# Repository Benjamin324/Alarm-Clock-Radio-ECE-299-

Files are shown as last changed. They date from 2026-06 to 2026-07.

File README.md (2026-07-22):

# ECE 299 Design Project
## University of Victoria

This is a design project for ECE 299, Introduction to Electrical Engineering Design, at the University of Victoria.

The goal of this design course is to prototype, develop, and manufacture a clock radio based on the Raspberry Pi Pico. Design elements include Python code running on the RPi, KiCAD schematic and PCB design, and SolidWorks enclosure design.

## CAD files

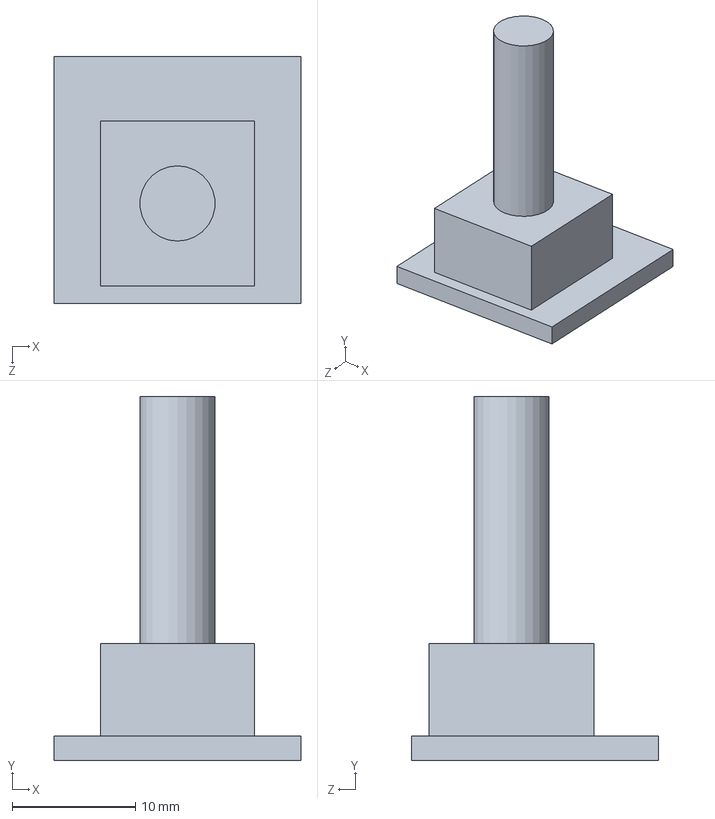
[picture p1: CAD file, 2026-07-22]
Enclosure/Encoder.SLDPRT
20.0 x 29.5 x 20.0 mm

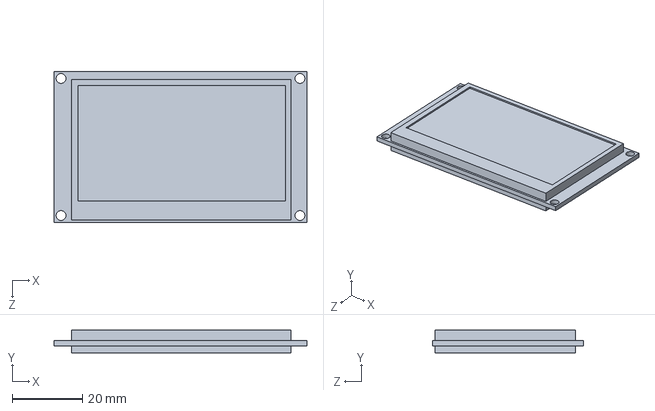
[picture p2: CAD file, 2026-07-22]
Enclosure/Display.SLDPRT
72.0 x 6.50 x 43.0 mm

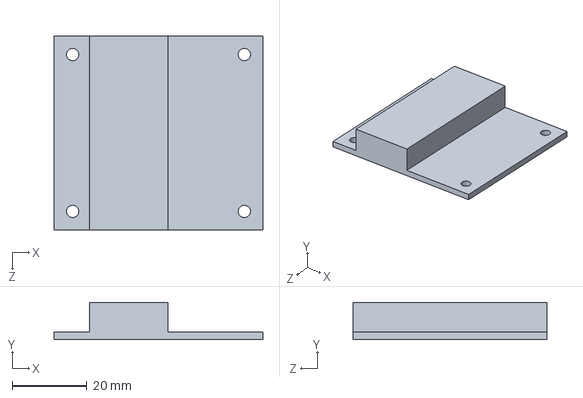
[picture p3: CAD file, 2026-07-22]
Enclosure/Mobo.SLDPRT
56.0 x 10.0 x 52.0 mm

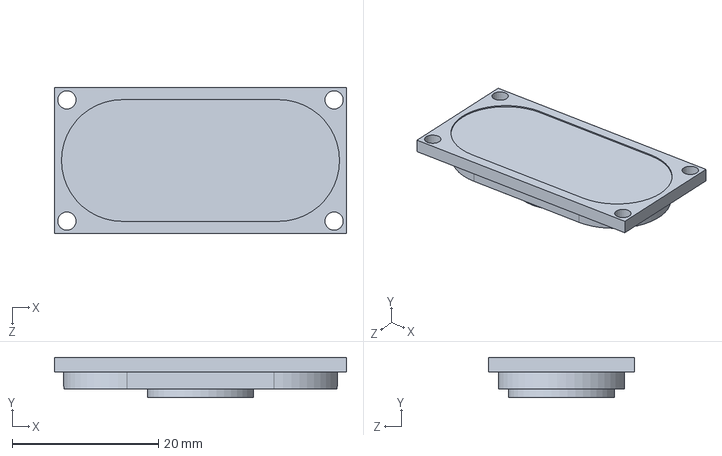
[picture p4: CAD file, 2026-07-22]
Enclosure/Speaker.SLDPRT
40.0 x 5.50 x 20.0 mm

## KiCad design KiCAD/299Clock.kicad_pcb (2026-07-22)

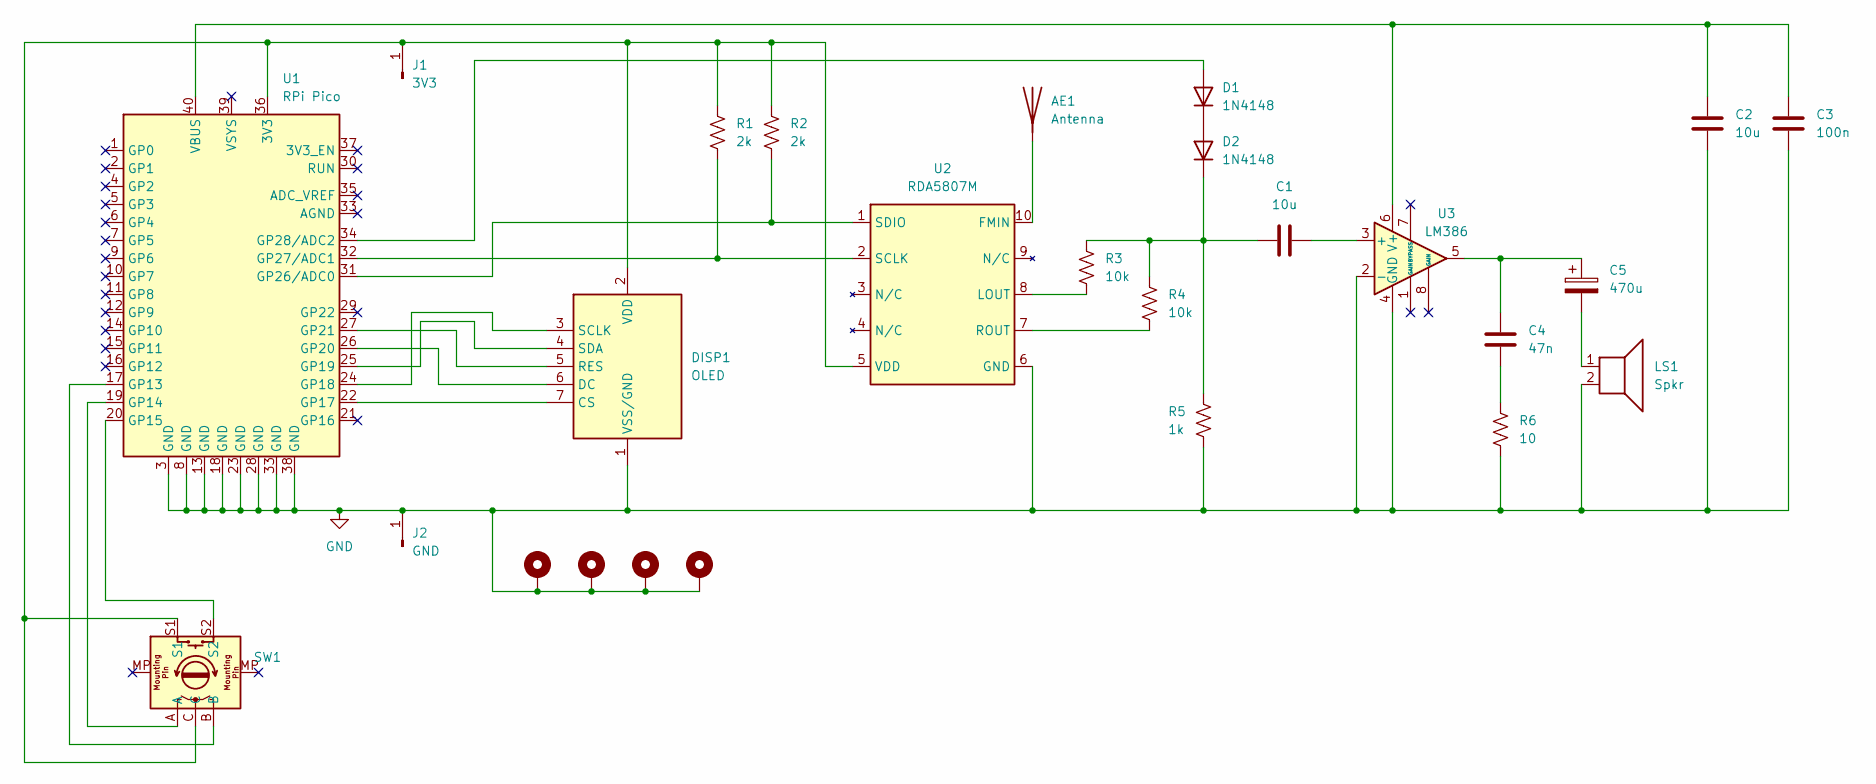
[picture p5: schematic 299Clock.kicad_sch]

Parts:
AE1: Antenna; SolderWire-0.1sqmm_1x01_D0.4mm_OD1mm
C1, C2: 10u; C_Rect_L7.0mm_W2.5mm_P5.00mm
C3: 100n; C_Rect_L7.0mm_W2.5mm_P5.00mm
C4: 47n; C_Rect_L7.0mm_W2.5mm_P5.00mm
C5: 470u; CP_Radial_D5.0mm_P2.50mm
D1, D2: 1N4148; D_DO-35_SOD27_P7.62mm_Horizontal
DISP1: OLED; PinHeader_1x07_P2.54mm_Vertical
H1, H2, H3, H4: MountingHole_Pad; MountingHole_3.2mm_M3_DIN965_Pad_TopBottom
J1: 3V3; SolderWire-0.1sqmm_1x01_D0.4mm_OD1mm
J2: GND; SolderWire-0.1sqmm_1x01_D0.4mm_OD1mm
LS1: Spkr; SolderWire-0.1sqmm_1x02_P3.6mm_D0.4mm_OD1mm
R1, R2: 2k; R_Axial_DIN0207_L6.3mm_D2.5mm_P7.62mm_Horizontal
R3, R4: 10k; R_Axial_DIN0207_L6.3mm_D2.5mm_P7.62mm_Horizontal
R5: 1k; R_Axial_DIN0207_L6.3mm_D2.5mm_P7.62mm_Horizontal
R6: 10; R_Axial_DIN0207_L6.3mm_D2.5mm_P7.62mm_Horizontal
SW1: PEC11R; PinHeader_1x05_P2.54mm_Vertical
U1: RPi Pico; RPi_Pico_TH
U2: RDA5807M; RDA5807M_Module_TH
U3: LM386; DIP-8_W7.62mm

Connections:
GND: C2.2, C3.2, DISP1.1 (VSS/GND), H1.1, H2.1, H3.1, H4.1, J2.1, LS1.2, R5.2, R6.2, U1.3 (GND), U1.8 (GND), U1.13 (GND), U1.18 (GND), U1.23 (GND), U1.28 (GND), U1.33 (GND), U1.38 (GND), U2.6 (GND), U3.2 (-), U3.4 (GND); also elsewhere on the board
unnamed: AE1.1 (A), U2.10 (FMIN)
unnamed: C1.1, D2.1 (K), R3.1, R4.1, R5.1
unnamed: C1.2, U3.3 (+)
unnamed: C2.1, C3.1, U1.40 (VBUS), U3.6 (V+)
unnamed: C4.1, C5.1, U3.5
unnamed: C4.2, R6.1
unnamed: C5.2, LS1.1
unnamed: D1.1 (K), D2.2 (A)
unnamed: D1.2 (A), U1.34 (GP28/ADC2)
unnamed 10: DISP1.2 (VDD), J1.1, R1.1, R2.1, SW1.C, SW1.S1, U1.36 (3V3), U2.5 (VDD); also elsewhere on the board
unnamed: DISP1.3 (SCLK), U1.24 (GP18)
unnamed: DISP1.4 (SDA), U1.25 (GP19)
unnamed: DISP1.5 (RES), U1.27 (GP21)
unnamed: DISP1.6 (DC), U1.26 (GP20)
unnamed: DISP1.7 (CS), U1.22 (GP17)
unnamed: R1.2, U1.32 (GP27/ADC1), U2.2 (SCLK)
unnamed: R2.2, U1.31 (GP26/ADC0), U2.1 (SDIO)
unnamed: R3.2, U2.8 (LOUT)
unnamed: R4.2, U2.7 (ROUT)
unnamed: SW1.A, U1.19 (GP14)
unnamed: SW1.B, U1.17 (GP13)
unnamed: SW1.S2, U1.20 (GP15)

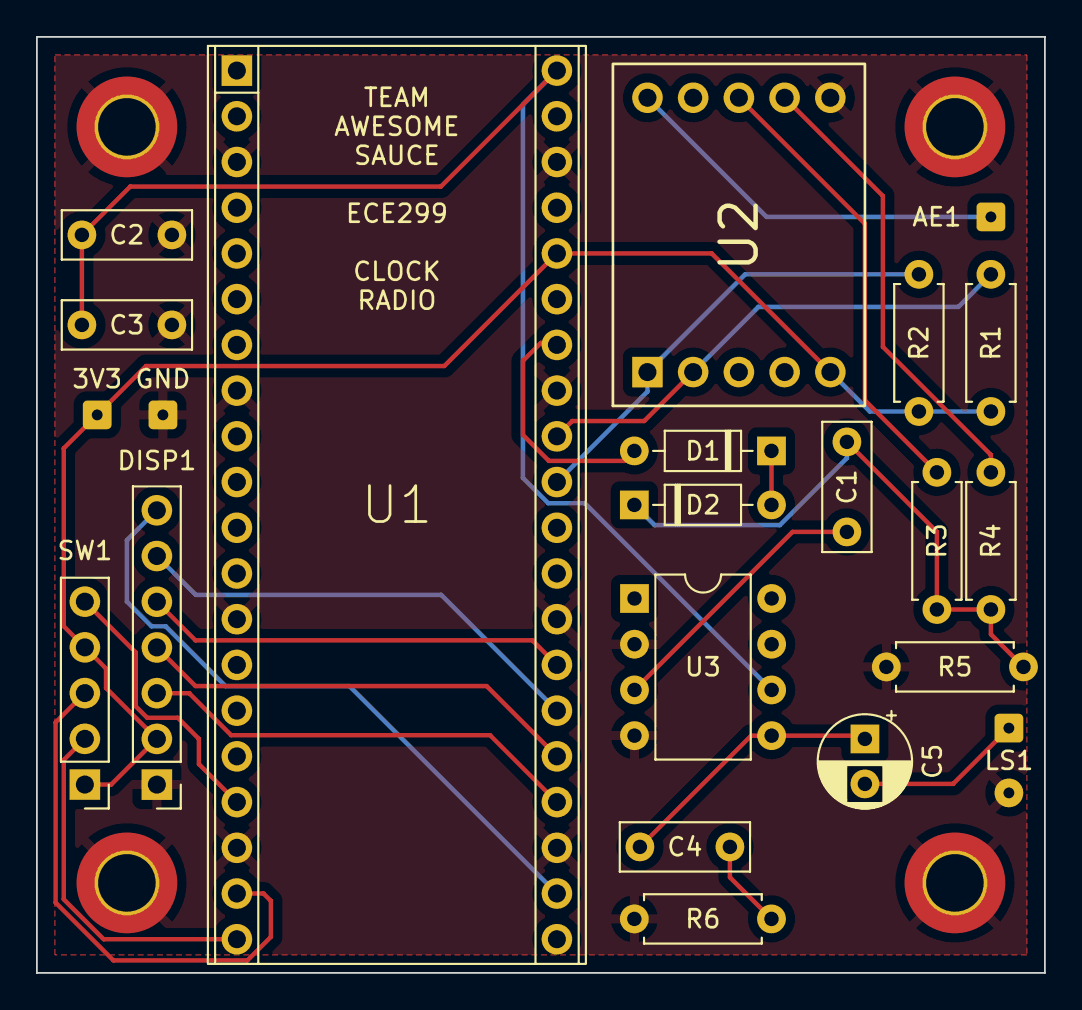
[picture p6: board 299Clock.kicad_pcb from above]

Board: 2 copper layers, 56.0 x 52.0 mm, 26 parts (0 on the bottom side), 23 nets.

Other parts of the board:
3V3: 3V3; SolderWire-0.1sqmm_1x01_D0.4mm_OD1mm
GND: GND; SolderWire-0.1sqmm_1x01_D0.4mm_OD1mm

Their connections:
GND: GND.1; also elsewhere on the board
unnamed 10: 3V3.1; also elsewhere on the board

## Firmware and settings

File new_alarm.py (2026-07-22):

        ### Import Libraries

from machine import Pin, SPI, I2C
from ssd1309 import SSD1309_SPI
import framebuf
import time


        ### Init Screen

SCREEN_WIDTH = 128
SCREEN_HEIGHT = 64
spi_sck = Pin(18)
spi_sda = Pin(19)
spi_res = Pin(21)
spi_dc  = Pin(20)
spi_cs  = Pin(17) 
SPI_DEVICE = 0
oled_spi = SPI( SPI_DEVICE, baudrate= 100000, sck= spi_sck, mosi= spi_sda )
oled = SSD1309_SPI( SCREEN_WIDTH, SCREEN_HEIGHT, oled_spi, spi_dc, spi_res, spi_cs, True )


        ### Init Radio

class Radio:
    def __init__( self, NewFrequency, NewVolume, NewMute ):
        self.Volume = 2
        self.Frequency = 88
        self.Mute = False
        self.SetVolume( NewVolume )
        self.SetFrequency( NewFrequency )
        self.SetMute( NewMute )
        self.i2c_sda = Pin(26)
        self.i2c_scl = Pin(27)
        self.i2c_device = 1 
        self.i2c_device_address = 0x10
        self.Settings = bytearray( 8 )
        self.radio_i2c = I2C( self.i2c_device, scl=self.i2c_scl, sda=self.i2c_sda, freq=200000)
        self.ProgramRadio()

    def SetVolume( self, NewVolume ):
        try:
            NewVolume = int( NewVolume )
        except:
            return( False )
        if ( not isinstance( NewVolume, int )):
            return( False )
        if (( NewVolume < 0 ) or ( NewVolume >= 16 )):
            return( False )
        self.Volume = NewVolume
        return( True )

    def SetFrequency( self, NewFrequency ):
        try:
            NewFrequency = float( NewFrequency )
        except:
            return( False )
        if ( not ( isinstance( NewFrequency, float ))):
            return( False )
        if (( NewFrequency < 88.0 ) or ( NewFrequency > 108.0 )):
            return( False )
        self.Frequency = NewFrequency
        return( True )
        
    def SetMute( self, NewMute ):
        try:
            self.Mute = bool( int( NewMute ))
        except:
            return( False )
        return( True )
    
    def ComputeChannelSetting( self, Frequency ):
        Frequency = int( Frequency * 10 ) - 870
        ByteCode = bytearray( 2 )
        ByteCode[0] = ( Frequency >> 2 ) & 0xFF
        ByteCode[1] = (( Frequency & 0x03 ) << 6 ) & 0xC0
        return( ByteCode )
    
    def UpdateSettings( self ):
        self.Settings = bytearray( 8 )
        if ( self.Mute ):
            self.Settings[0] = 0x80
        else:
            self.Settings[0] = 0xC0
        self.Settings[1] = 0x09 | 0x04
        self.Settings[2:3] = self.ComputeChannelSetting( self.Frequency )
        self.Settings[3] = self.Settings[3] | 0x10
        self.Settings[4] = 0x04
        self.Settings[5] = 0x00
        self.Settings[6] = 0x84
        self.Settings[7] = 0x80 + self.Volume
        self.Settings = self.Settings[:8]

    def ProgramRadio( self ):
        self.UpdateSettings()
        self.radio_i2c.writeto( self.i2c_device_address, self.Settings )
        
    def GetSettings( self ):
        self.RadioStatus = self.radio_i2c.readfrom( self.i2c_device_address, 256 )
        if (( self.RadioStatus[0xF0] & 0x40 ) != 0x00 ):
            MuteStatus = False
        else:
            MuteStatus = True
        VolumeStatus = self.RadioStatus[0xF7] & 0x0F
        FrequencyStatus = (( self.RadioStatus[0x00] & 0x03 ) << 8 ) | ( self.RadioStatus[0x01] & 0xFF )
        FrequencyStatus = ( FrequencyStatus * 0.1 ) + 87.0
        if (( self.RadioStatus[0x00] & 0x04 ) != 0x00 ):
            StereoStatus = True
        else:
            StereoStatus = False
        return( MuteStatus, VolumeStatus, FrequencyStatus, StereoStatus )

fm_radio = Radio( 101.9, 5, False )


        ### Init Encoder

a = Pin(14, Pin.IN, Pin.PULL_DOWN)
b = Pin(13, Pin.IN, Pin.PULL_DOWN)
button = Pin(15, Pin.IN, Pin.PULL_DOWN)
last_a = a.value()


def debounce():
    global deb_clock
    
    deb_current = time.ticks_ms() # get time of press
    if deb_current > (deb_clock + deb_time): # compare to debounce counter
        deb_clock = deb_current # reset debounce counter
        return True # sucessful click
    else:
        return False # rejected (debounced) click


def encoder_irq(pin):
    global last_a
    current_a = a.value()
    if debounce():
        if current_a != last_a:
                if b.value() != current_a:
                    left_turn()
                else:
                    right_turn()


def button_irq(pin):
    if debounce():
        centre_press()
        

a.irq(trigger=Pin.IRQ_RISING,
      handler=encoder_irq)

button.irq(trigger=Pin.IRQ_RISING,
      handler=button_irq)


        ### Global Vars

mode = 0                       # tracks which screen mode is active (always %4)
menu_sel = 0                   # tracks which menu option is highlighted w/ carrot
set_time = [0,0]               # temp time array for setting alarm/time (elements are always %12)
alarm = [0,0]
set_seg = 0                    # tracks which time segment (H/M) is being set
set_mode = False               # tracks if current set_time is to be written to clock (False) or to alarm (True)
time_format = True
alarm_set = True
deb_time = 40                  # Debounce time in ms
deb_clock = 0                  # Timer for debouncing script


        ### UI Button Funcs

def right_turn():
    global mode, menu_sel, set_time
    
    if mode == 0: # Main
        vol = fm_radio.GetSettings()[1] # fetch current volume
        if vol == 15: # 15 is max volume
            pass
        else:
            vol += 1 # increment volume
            if ( fm_radio.SetVolume( vol ) == True ): # write vol value to module
                fm_radio.ProgramRadio()
            else:
                print( "Invalid volume level" )
            
    
    elif mode == 1: # Settings
        menu_sel += 1 # increment highlighted menu option
        
    elif mode == 2: # Timeset
        set_time[(set_seg)] += 1 # increment the relevant time segment in the temp set_time array
            
    elif mode == 3: # Radioset
        freq = fm_radio.GetSettings()[2] # fetch current tuned frequency
        print(freq)
        if freq == 108.0: # max freq
            pass
        else:
            freq += 0.1 # increment freq
            if ( fm_radio.SetFrequency( freq ) == True ): # write freq to module
                fm_radio.ProgramRadio()
            else:
                print( "Invalid frequency" )
    
    else:
        print("invalid mode in right_turn()") # mode should not be > 3
    
    print("right turn")
    return
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

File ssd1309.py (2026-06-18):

# MicroPython SSD1306 OLED driver, I2C and SPI interfaces

from micropython import const
import framebuf


# register definitions
SET_CONTRAST = const(0x81)
SET_ENTIRE_ON = const(0xA4)
SET_NORM_INV = const(0xA6)
SET_DISP = const(0xAE)
SET_MEM_ADDR = const(0x20)
SET_COL_ADDR = const(0x21)
SET_PAGE_ADDR = const(0x22)
SET_DISP_START_LINE = const(0x40)
SET_SEG_REMAP = const(0xA0)
SET_MUX_RATIO = const(0xA8)
SET_IREF_SELECT = const(0xAD)
SET_COM_OUT_DIR = const(0xC0)
SET_DISP_OFFSET = const(0xD3)
SET_COM_PIN_CFG = const(0xDA)
SET_DISP_CLK_DIV = const(0xD5)
SET_PRECHARGE = const(0xD9)
SET_VCOM_DESEL = const(0xDB)
SET_CHARGE_PUMP = const(0x8D)

# Subclassing FrameBuffer provides support for graphics primitives
# http://docs.micropython.org/en/latest/pyboard/library/framebuf.html
class SSD1309(framebuf.FrameBuffer):
    def __init__(self, width, height, external_vcc):
        self.width = width
        self.height = height
        self.external_vcc = external_vcc
        self.pages = self.height // 8
        self.buffer = bytearray(self.pages * self.width)
        super().__init__(self.buffer, self.width, self.height, framebuf.MONO_VLSB)
        self.init_display()

    def init_display(self):
        self.poweron()
        self.write_cmd( 0xA4 )
        self.fill(0)
        self.rotate(1)
        self.show()

    def poweroff(self):
        self.write_cmd( SET_DISP )

    def poweron(self):
        self.write_cmd( SET_DISP | 0x01 )

    def contrast(self, contrast):
        self.write_cmd(SET_CONTRAST)
        self.write_cmd(contrast)

    def invert(self, invert):
        self.write_cmd(SET_NORM_INV | (invert & 1))

    def rotate(self, rotate):
        self.write_cmd(SET_COM_OUT_DIR | ((rotate & 1) << 3))
        self.write_cmd(SET_SEG_REMAP | (rotate & 1))

    def show(self):
        x0 = 0
        x1 = self.width - 1
        if self.width != 128:
            # narrow displays use centred columns
            col_offset = (128 - self.width) // 2
            x0 += col_offset
            x1 += col_offset
            
        self.write_cmd( SET_MEM_ADDR )
        self.write_cmd( 0x00 )
        
        self.write_cmd( SET_COL_ADDR )
        self.write_cmd( x0 )
        self.write_cmd( x1 )
        
        self.write_cmd( SET_PAGE_ADDR )
        self.write_cmd( 0 )
        self.write_cmd( self.pages - 1 )

        self.write_data(self.buffer)


# class SSD1309_I2C(SSD1309):
#     def __init__(self, width, height, i2c, addr=0x3C, external_vcc=False):
#         self.i2c = i2c
#         self.addr = addr
#         self.temp = bytearray(2)
#         self.write_list = [b"\x40", None]  # Co=0, D/C#=1
#         super().__init__(width, height, external_vcc)
# 
#     def write_cmd(self, cmd):
#         self.temp[0] = 0x80  # Co=1, D/C#=0
#         self.temp[1] = cmd
#         self.i2c.writeto(self.addr, self.temp)
# 
#     def write_data(self, buf):
#         self.write_list[1] = buf
#         self.i2c.writevto(self.addr, self.write_list)


class SSD1309_SPI(SSD1309):
    def __init__(self, width, height, spi, dc, res, cs, external_vcc=False):
        self.rate = 10 * 1024 * 1024
        dc.init(dc.OUT, value=0)
        res.init(res.OUT, value=0)
        cs.init(cs.OUT, value=1)
        self.spi = spi
        self.dc = dc
        self.res = res
        self.cs = cs
        import time

        self.res(1)
        time.sleep_ms(1)
        self.res(0)
        time.sleep_ms(10)
        self.res(1)
        super().__init__(width, height, external_vcc)

    def write_cmd(self, cmd):
        self.spi.init(baudrate=self.rate, polarity=0, phase=0)
        self.cs(1)
        self.dc(0)
        self.cs(0)
        self.spi.write(bytearray([cmd]))
        self.cs(1)

    def write_data(self, buf):
        self.spi.init(baudrate=self.rate, polarity=0, phase=0)
        self.cs(1)
        self.dc(1)
        self.cs(0)
        self.spi.write(buf)
        self.cs(1)

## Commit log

2026-06-06 minmal encoder functionality'
2026-06-11 Add files via upload
    New script for managing Interrupt Requests and control over the UI. This code will be more compatible between a button interface and a rotary encoder
2026-06-20 Updated KiCAD files
    [299Clock_v2.kicad_pcb, 299Clock_v2.kicad_sch]
2026-06-20 Creating new KiCAD folder
    [299Clock.kicad_pcb]
2026-06-24 Added test points to PCB
    [299Clock_v2.kicad_pcb, 299Clock_v2.kicad_sch]
2026-06-24 Began adding traces to PCB
    [299Clock.kicad_pcb]
2026-06-24 Finished traces, routed sw, add ground planes
    [299Clock.kicad_pcb, 299Clock.kicad_sch]
2026-07-07 revision of PCB and exported gerber
    [299Clock.kicad_pcb, 299Clock.kicad_sch]
2026-07-14 Create enclosure.md
    New folder for modelling
2026-07-14 Added SolidWorks part files
    Adding SolidWorks part files for the display, speaker, and encoder
    [Display.SLDPRT, Encoder.SLDPRT, Speaker.SLDPRT]
2026-07-14 Added mainboard part file
    [Mobo.SLDPRT]
2026-07-19 Add files via upload
    3d Print penguin. Wrong dimensions for bosses
